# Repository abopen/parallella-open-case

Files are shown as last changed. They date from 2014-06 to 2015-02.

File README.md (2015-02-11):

# Parallella Open Case and Cooling Kit

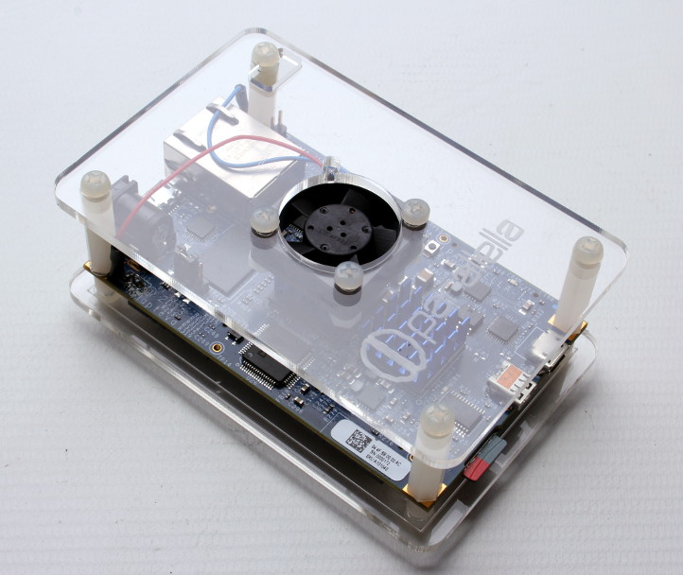
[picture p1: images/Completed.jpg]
A Parallella board fitted in a PARC-01 case


The [PARC-01 kit](http://abopen.com/PARC-01) is a simple but elegant case based on the "[sick of beige](http://dangerousprototypes.com/docs/Sick_of_Beige_basic_case_v1)" design and includes a DC fan to keep the [Parallella](http://www.parallella.org/) board cool (heatsink required also). It can be bought from [Ground Electronics](http://groundelectronics.com).

## Repository contents

The case design is provided in the following formats:

* Adobe Illustrator (source)
* SVG
* PDF
* DXF

The top and bottom panels are laser cut from 3mm clear acrylic.

## Bill of materials

In addition to the acrylic parts the PARC-01 kit contains:

| Qty | Item |
| --- | --- |
|  1  | 25x25x8mm 5VDC fan |
|  8  | M3 16mm nylon screw |
|  4  | M3 12mm nylon screw |
|  4  | M3 nylon nut |
|  4  | M3 20mm nylon hex threaded spacer |
|  4  | 3.2mm ID x 3mm circular nylon spacer|
|  4  | Clear 10mm diameter rubber foot/bumper|

## Fan power supply

J15 must be fitted in order to take power for the fan from the Parallella board mounting hole pads.

If the jumper is not already fitted, first locate J15.

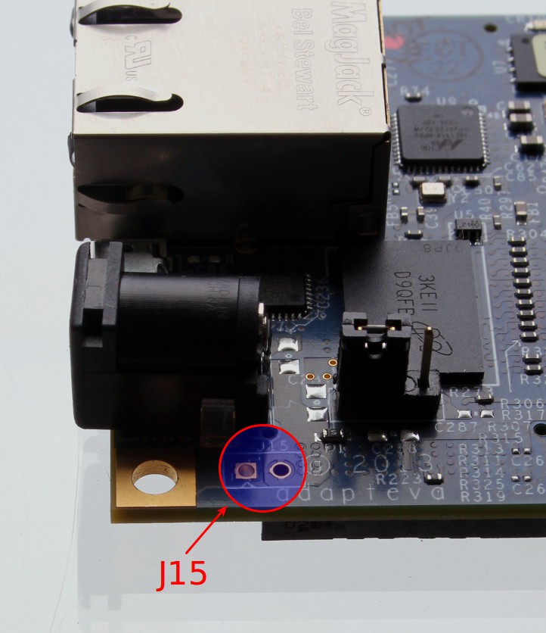
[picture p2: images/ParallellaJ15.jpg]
J15 open
 

1. Cut a ~6mm or so piece of solid core hook-up wire and bend this into a U shape, with the two ends around 3mm apart. 

2. Insert this into J15, but note that it may not drop all the way in as there is a Samtec connector directly under one of the pads.

3. Solder the link in place from the top side of the board.

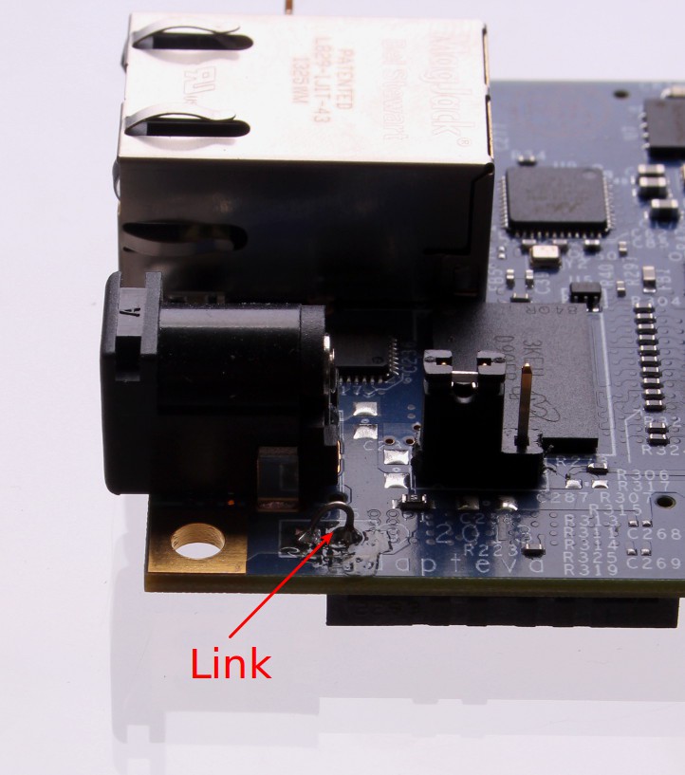
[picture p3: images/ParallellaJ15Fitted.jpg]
J15 fitted


## Assembly

1. Remove the protective plastic from the acrylic panels.

2. Place the top panel face down (writing going the wrong way).

3. Place the fan on top, with the label facing upwards and the leads pointing towards the hole for the UART header.

4. Fix the fan in place with 4x M3 16mm nylon screws and 4x M3 nylon nuts.

5. Use wire cutters to trim the screws close to the nuts.

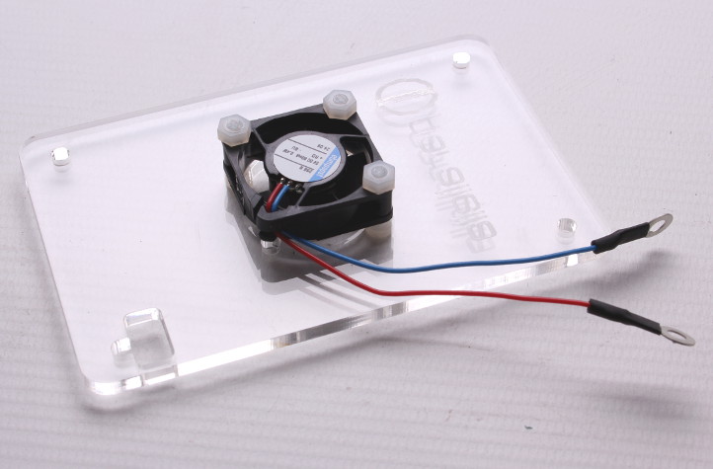
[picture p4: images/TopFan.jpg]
Top panel with fan fitted
   

6. Fix the rubber feet to the base panel, just inside — but not covering! — the four holes.

7. Push the remaining M3 16mm nylon screws up through the base panel, and drop the 3mm circular spacers on top.

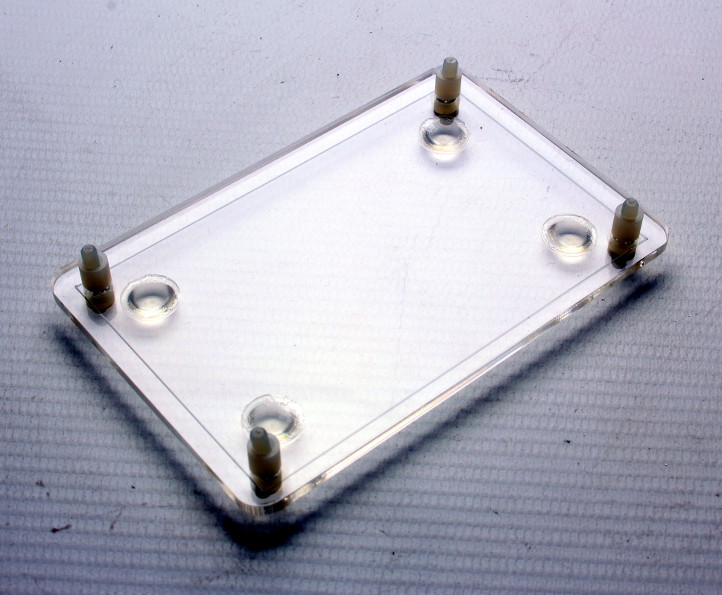
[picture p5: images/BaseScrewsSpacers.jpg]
Base panel with screws and circular spacers
   

8. Place the Parallella board on top of the spacers.

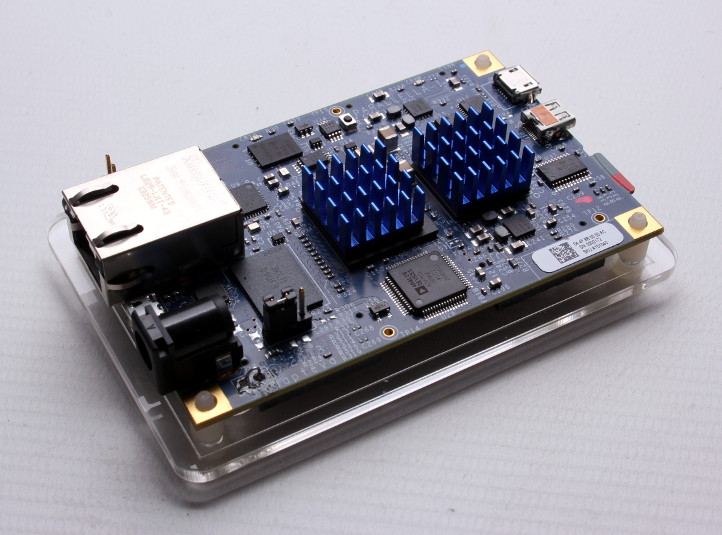
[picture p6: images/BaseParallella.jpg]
Base with Parallella
   

9. Ensure that a suitable heatink(s) is fitted, such as the "slab" heatsink that has been supplied with boards ordered since 10th July 2014, or two smaller heatsinks as shown above. Please note that heatinks are no longer supplied with this kit as of v1.2.

10. Connect the fan +ve solder tag (red wire) to the mounting hole pad next to the barrel jack power connector.

11. Connect the fan -ve solder tag (blue wire) to the mounting hole pad next to the Ethernet connector.

16. Screw the four nylon hex spacers down onto the screws.

17. Place the top panel on the hex spacers and fix in place with 4x M3 12mm nylon screws. 

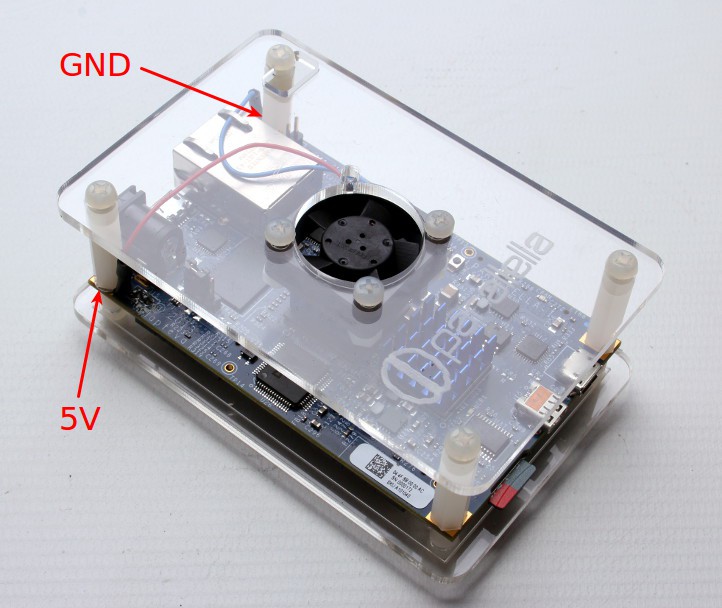
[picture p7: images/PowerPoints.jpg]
Fan power supply points
   

## Changelog

| Version | Date | Summary |
|---|---|---|
| 1.2 | 11/02/15 | Heatsinks are no longer included. |
| 1.1 | Summer 14| Larger Zynq heatsink, and fan with 4 mounting holes and pre-terminated leads. |
| 1.0 | 25/06/14 | Initial version. |

## Licence

Parallella Open Case and Cooling Kit copyright 2014, 2015 [AB Open Ltd](http://abopen.com).

<br />This work is licensed under a <a rel="license" href="http://creativecommons.org/licenses/by/4.0/">Creative Commons Attribution 4.0 International License</a>.

## Thanks

With thanks to [Oomlout](http://oomlout.co.uk/) for their help with design and prototyping.

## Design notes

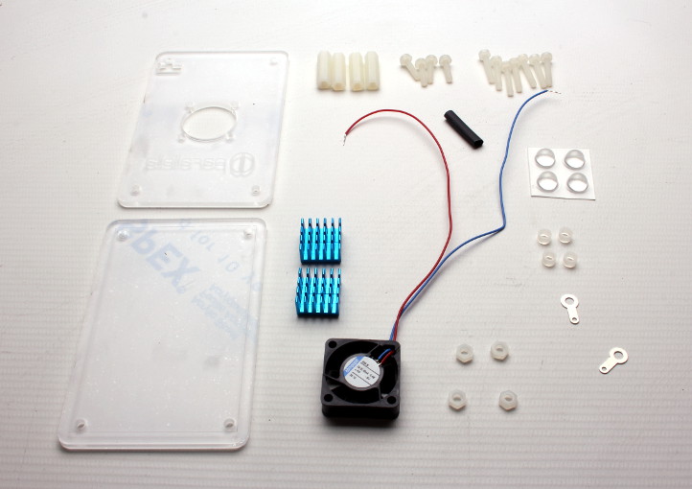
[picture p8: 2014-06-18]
images/Contents.jpg

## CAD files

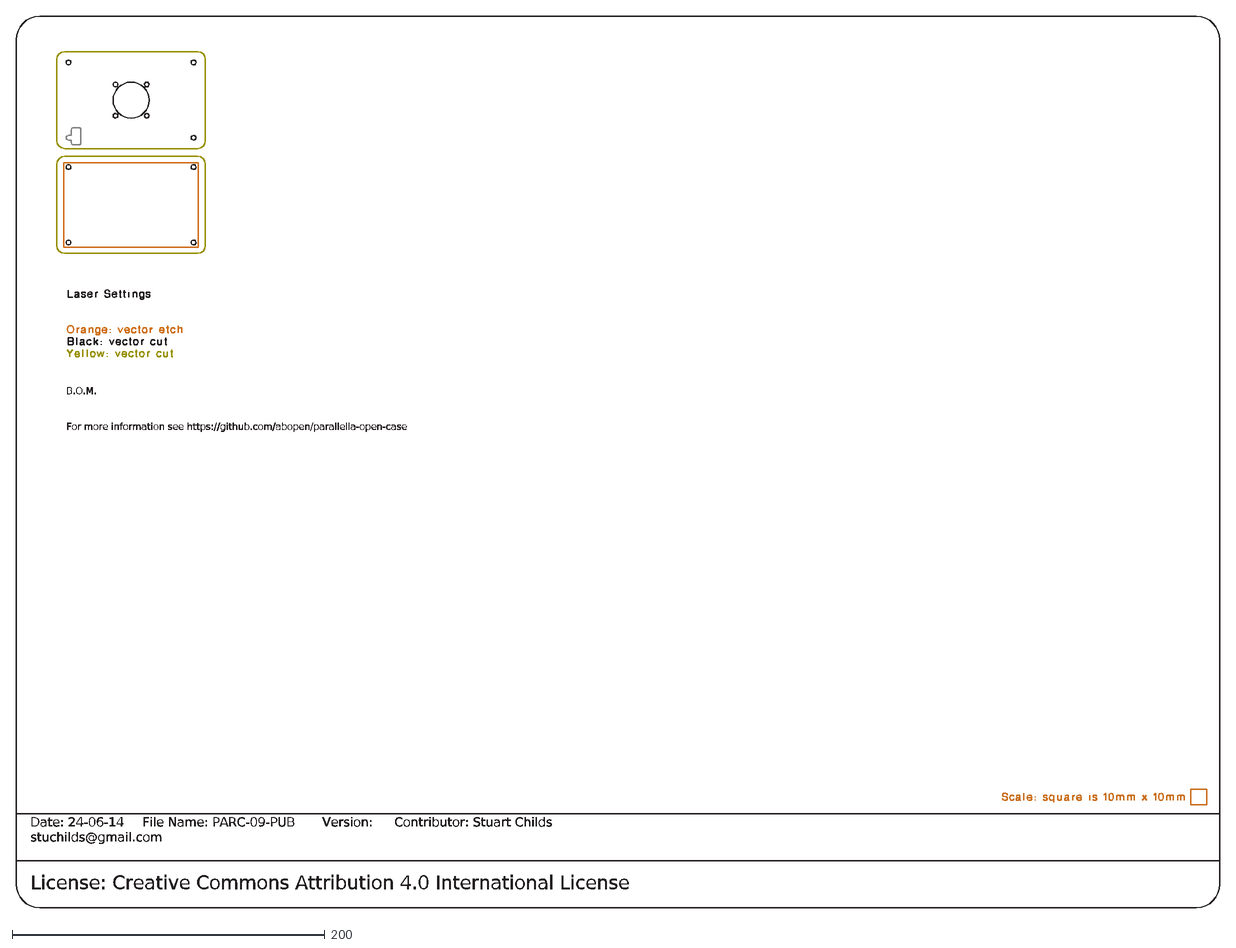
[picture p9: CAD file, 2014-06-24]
PARC-01.dxf
Date: 24-06-14 File Name: PARC-09-PUB Version: Contributor: Stuart Childs stuchilds@gmail.com
License: Creative Commons Attribution 4.0 International License
B.O.M.
For more information see https://github.com/abopen/parallella-open-case

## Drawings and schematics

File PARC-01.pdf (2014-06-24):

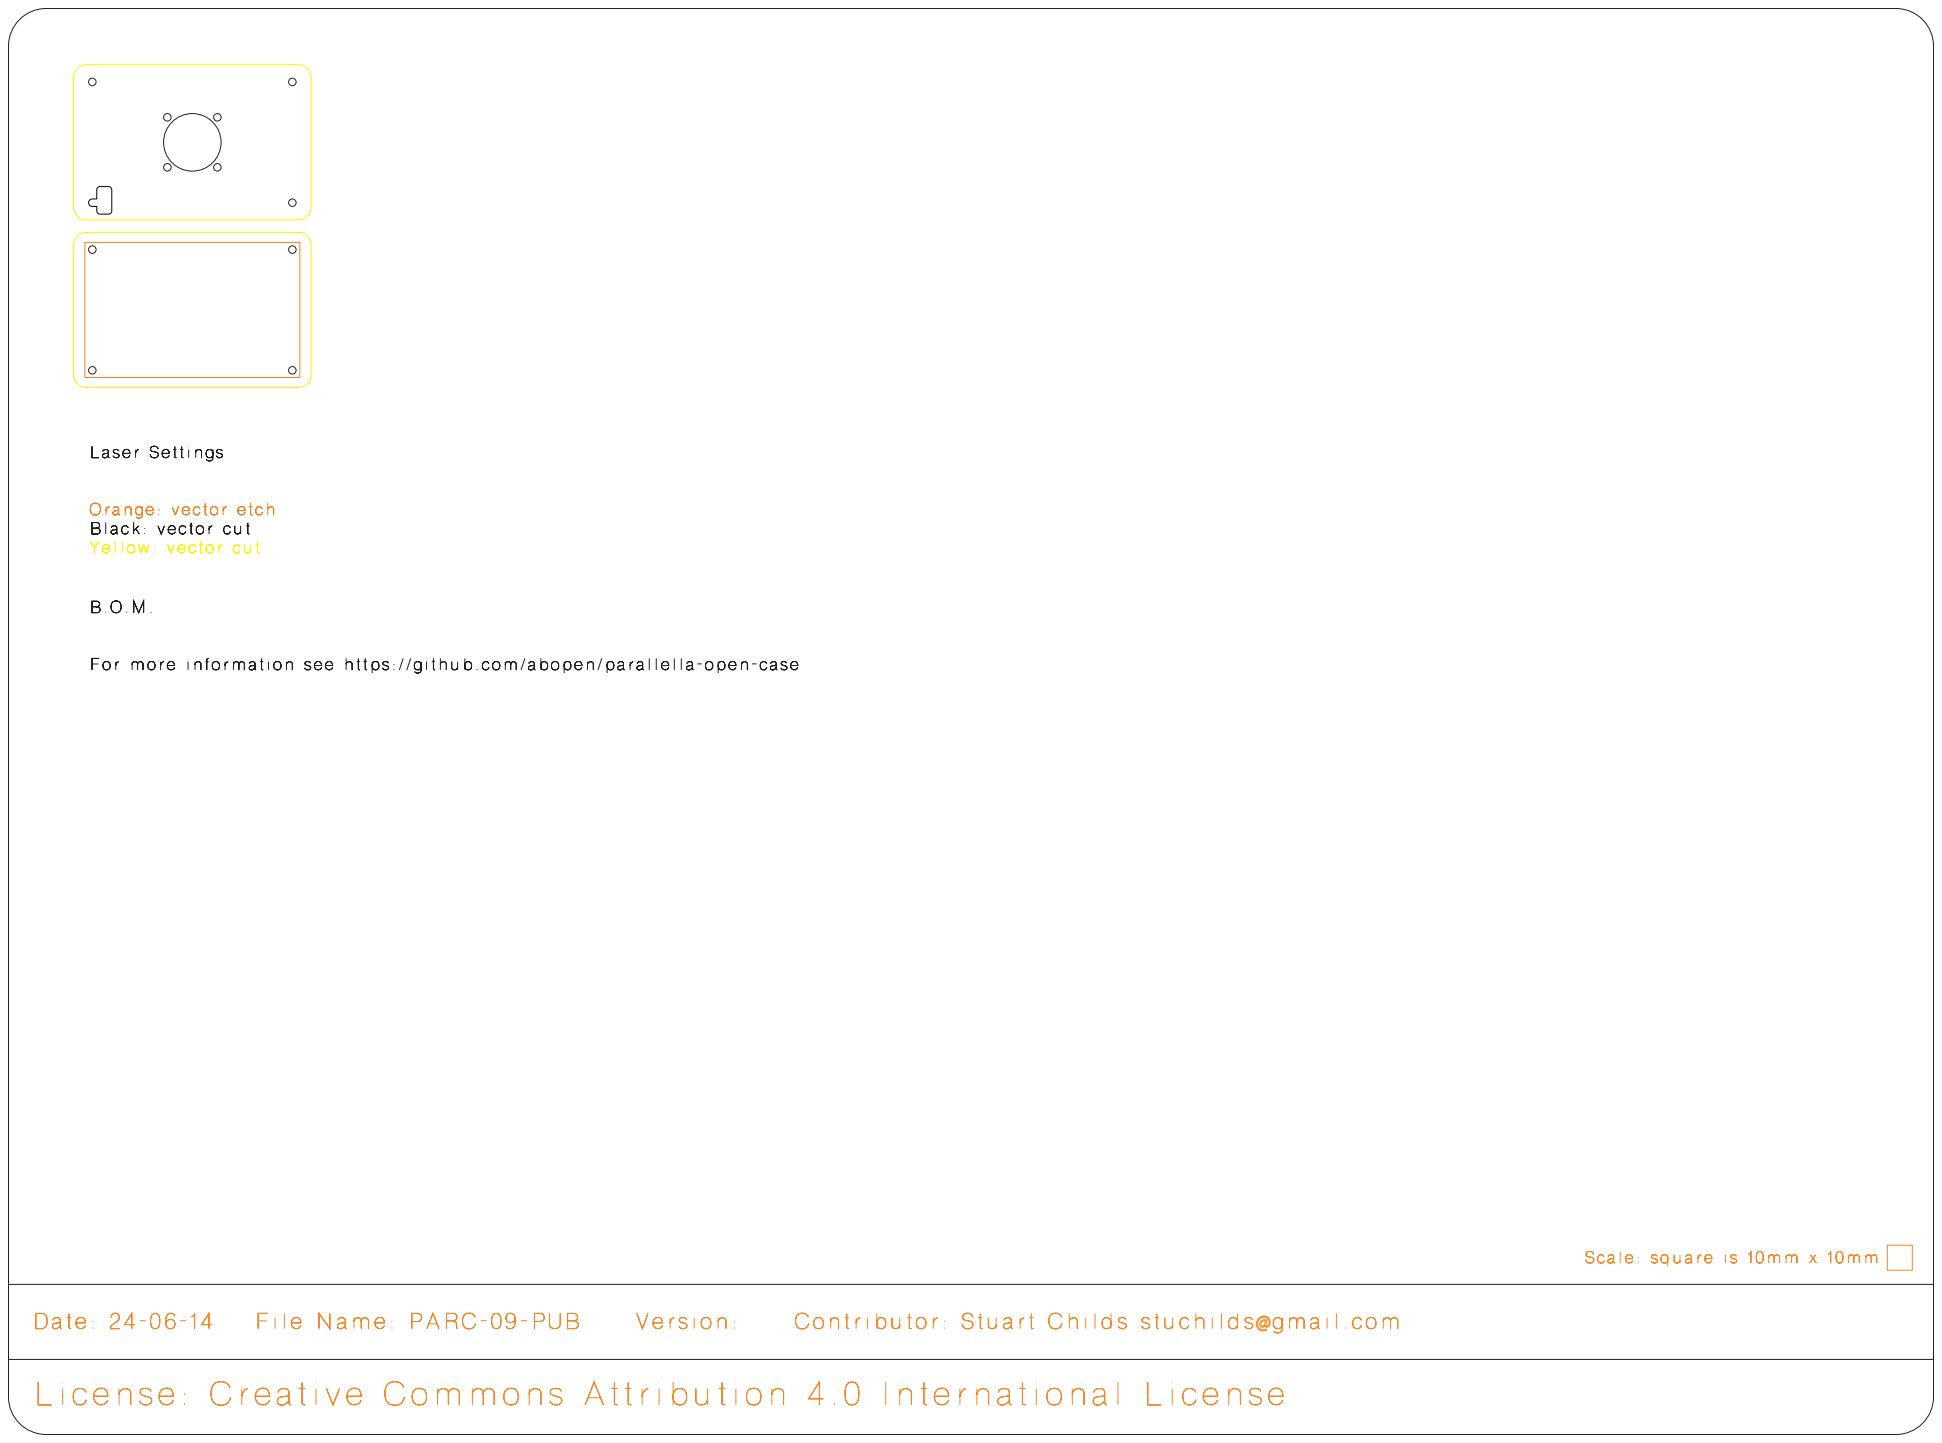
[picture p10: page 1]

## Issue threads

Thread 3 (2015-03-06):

screws do not fit with large heatsink supplied with new parallela boards

jonnew, 2015-03-06:
The 16 mm screws to hold the fan in place protrude too far down and run into the large, black heatsink that is supplied with the parallela board. The 12 mm screws work great, so ship kits with 8X 12 mm screws and 4X 16mm screws and that should fit everyone's needs.

9600, 2015-03-06:
Thanks for the feedback, we'll look at the possibility of updating the BOM. However, since these are nylon you can just snip the bottom off the screws securing the fan in place.

jonnew, 2015-03-06:
True enough.

Closed 2015-03-06.

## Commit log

2014-06-24 Added laser design files
    [PARC-01.dxf]
2015-02-09 Updated BOM and instructions to reflect v1.1 kit
2015-02-11 Heatsinks no longer included.

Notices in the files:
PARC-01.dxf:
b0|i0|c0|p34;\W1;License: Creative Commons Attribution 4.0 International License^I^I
